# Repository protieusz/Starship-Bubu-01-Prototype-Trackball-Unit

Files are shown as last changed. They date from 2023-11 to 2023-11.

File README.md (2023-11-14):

# Starship-Bubu-01-Prototype-Trackball-Unit
Solo trackball unit powered by my Omega Supreme all in one PMW3660 sensor trackball, PER56, RP2040 integrated module.

Trackball ball support, encoder support and encoder knob support are all printed from Ariamelon's Kiwano VIK module in her GitHub.  

Initially this project was just going to be a working concept prototype and in the end it turns out to be a very functional working build.

Be warned: This project build requires lots of advanced soldering technical skills, lots of dexterityl, time and effort.

QMK source code was borrowed from Aki27's Bally build. I just copy and pasted most of it and adjust minor stuff. No support will be given since I am not well verse in QMK. 

In order to build this Starship Bubu, you would need the Bubu PCB itself and an OmegaSupreme REV 4 module which contains the RP2040 mcu, PMW3360 sensor and PER56 encoder.

# Starship Bubu-01 Prototype got featured on https://kbd.news/Starship-Bubu-OmegaSupreme-2184.html

Nov 11,2023 Update:

Upgraded with a janky case. 
https://www.instagram.com/p/CzhdMmdv5LE/?igshid=YzE4YTliZjNlMA==

Uploaded both STEP and STLs for the case.  I already lost a lot of brain cells designing the case.  Currently the case needs to be sandwiched hot glue together or whatever glue you use.  I hot glue just in case shit happens and I have to take apart and fix stuff.  You can modified the STEP files to your likely to make the case more secure.  I am not going to do any more tinkering with this prototype trackball anymore. Do so at your own risk.

As for the trackball support low profile holder, base PER56 encoder part and the ribbed knob please refer to AriaMelon's Kiwano GitHub for her 3DP STL files. https://github.com/Ariamelon/Kiwano/tree/main/3DP 

The trackball/RP2040 module aka the Omega Supreme I use for building the Starship Bubu-01 Prototype is from my OmegaSupreme Rev 4 https://github.com/protieusz/OmegaSupreme 
REV 4 with the corrected copper plated mount holes have been uploaded to the OmegaSupreme GitHub so print and assemble that one.  As always print at your own risk and for some reason when I install my PER56 encoder the footprint doesn't quite fit so I had to snip off the 2 black plastic anchors and bent one of the anchors a bit in order to fit in. Tight fit but it works.  The PER56 encoder was somehow flipped as per Sadek of Fingerpunch.  I don't feel like going back to flip the footprint and re-route again.  

Here is a picture from Sadek's Fingerpunch discord channel show which plastic anchors to snip off. [Fingerpunch](https://discord.com/channels/939959680611020840/1104738004574158968/1171529178949103666)

Screenshot 2023-11-12 at 12 56 26 AM

A full build guide will be uploaded soon.

Full Production Final Build Pics:





Build & Test Fit Process:










Starship Bubu PCB












Nov 3, 2023
Final product is still being testing and still waiting for PER56 encoder to arrive. Firmware working flawlessly. Once the PER56 final piece arrives, then Starship Bubu-01 Prototype will be fully assembled and ready.
Design gerbers will be made public and since this solo trackball is designed using EasyEDA, Kicad pcb file conversion will be a headache so the pcb file will not be released. However, schematic pdf and BOM will be release. The parts are manually hand solder so if you want to print this pcb, be prepared to advanced soldering skills to solder 0402 size components and lots of wiring soldering. Print and use as your own risk! No support will be provided. Please follow the below licensing if you want to modify, use, etc.  Omega Supreme module BOM and gerber files will be release if its own repository which will be updated later on.

Prototype Test Fit Look:



Fusion360 Design Render:

Screenshot 2023-10-26 at 3 34 44 PM

# License

</a></p>

You are free to:

Share — copy and redistribute the material in any medium or format

Adapt — remix, transform, and build upon the material

The licensor cannot revoke these freedoms as long as you follow the license terms.
Under the following terms:

Attribution — You must give appropriate credit, provide a link to the license, and indicate if changes were made. You may do so in any reasonable manner, but not in any way that suggests the licensor endorses you or your use.

NonCommercial — You may not use the material for commercial purposes.

ShareAlike — If you remix, transform, or build upon the material, you must distribute your contributions under the same license as the original.

No additional restrictions — You may not apply legal terms or technological measures that legally restrict others from doing anything the license permits.

Starship Bubu-01 Prototype by ProtieusKeebs is licensed under [CC BY-NC-SA 4.0](https://creativecommons.org/licenses/by-nc-sa/4.0/?ref=chooser-v1)

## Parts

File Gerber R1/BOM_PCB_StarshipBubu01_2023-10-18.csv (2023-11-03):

ID | Name | Designator | Footprint | Quantity | Manufacturer Part | Manufacturer | Supplier | Supplier Part | Price | link
1 |  | U13 | PL9823LED | 1
2 | NO | +5V,D+,D-,GND,GP6COL0,GP12COL1,GP13COL2,GP14ROW1,GP15ROW0,+5VOS,DINOS | PIN 1-PIN | 11
3 | PRTR5V0U2X,215 | D1-ESD | SOT-143_L2.9-W1.3-P1.92-LS2.3-BR | 1 | PRTR5V0U2X,215 | Nexperia(安世) | LCSC | C12333 | 0.162 | https://item.szlcsc.com/280548.html
4 | BSMD0805-020-15V | F1-FUSE | F0805 | 1 | BSMD0805-020-15V | BHFUSE(佰宏) | LCSC | C883103 | 0.045 | https://item.szlcsc.com/343298.html
5 | 5.1kΩ | R1-5.1K,R2-5.1K | R0402 | 2 | 0402WGF5101TCE | UNI-ROYAL(厚声) | LCSC | C25905 | 0.001 | https://item.szlcsc.com/323315.html
6 | TYPE-C-31-M-12 | USBC1 | USB-C_SMD-TYPE-C-31-M-12 | 1 | TYPE-C-31-M-12 | 韩国韩荣 | LCSC | C165948 | 0.216 | https://so.szlcsc.com/global.html?c=&k=C165948
7 | SM4007PL | D000,D002,D100,D101,D102 | SOD-123F_L2.8-W1.8-LS3.7-RD | 5 | SM4007PL | MDD | LCSC | C64898 | 0.007 | https://item.szlcsc.com/60254.html
8 | Switch | K000,K002,K100,K101,K102 | CHERRY_MX_100_MILLMAX | 5
9 |  | U14 | PL9823LED | 1

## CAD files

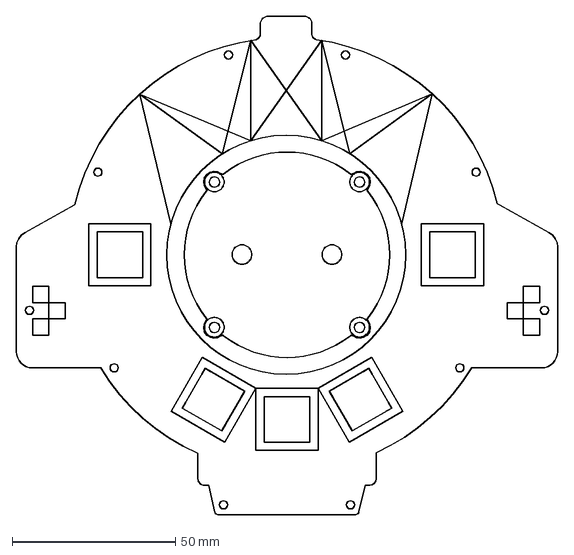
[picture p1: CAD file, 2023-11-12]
StarshipBubuPCBwHoles.dxf
166.0 x 152.8 mm

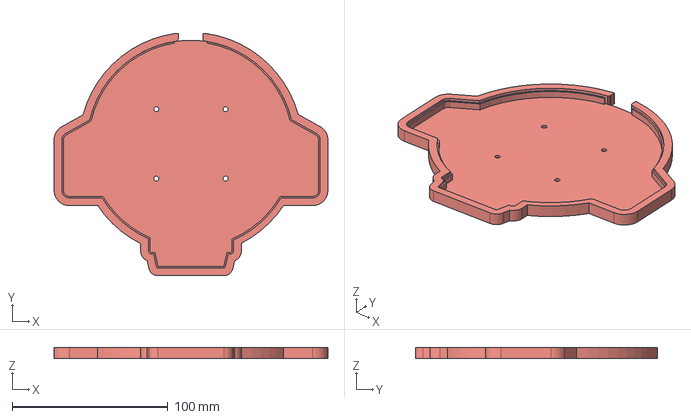
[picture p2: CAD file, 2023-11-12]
Case STEP/BubuBottomPlateCase.step
176.0 x 155.7 x 7.20 mm

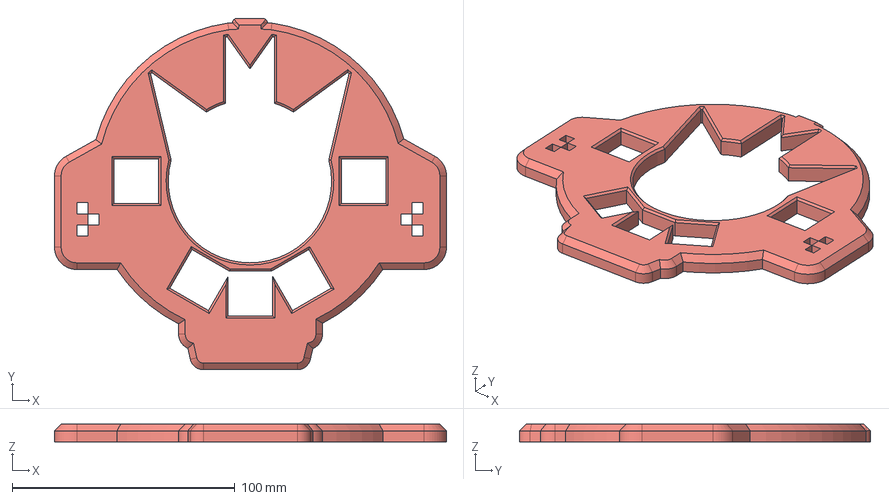
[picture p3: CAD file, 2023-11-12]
Case STEP/BubuTopCase.step
176.0 x 157.8 x 8.00 mm

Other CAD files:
Corrected STLs/BubuBottomPlateCase.stl
Corrected STLs/BubuTopCase.stl

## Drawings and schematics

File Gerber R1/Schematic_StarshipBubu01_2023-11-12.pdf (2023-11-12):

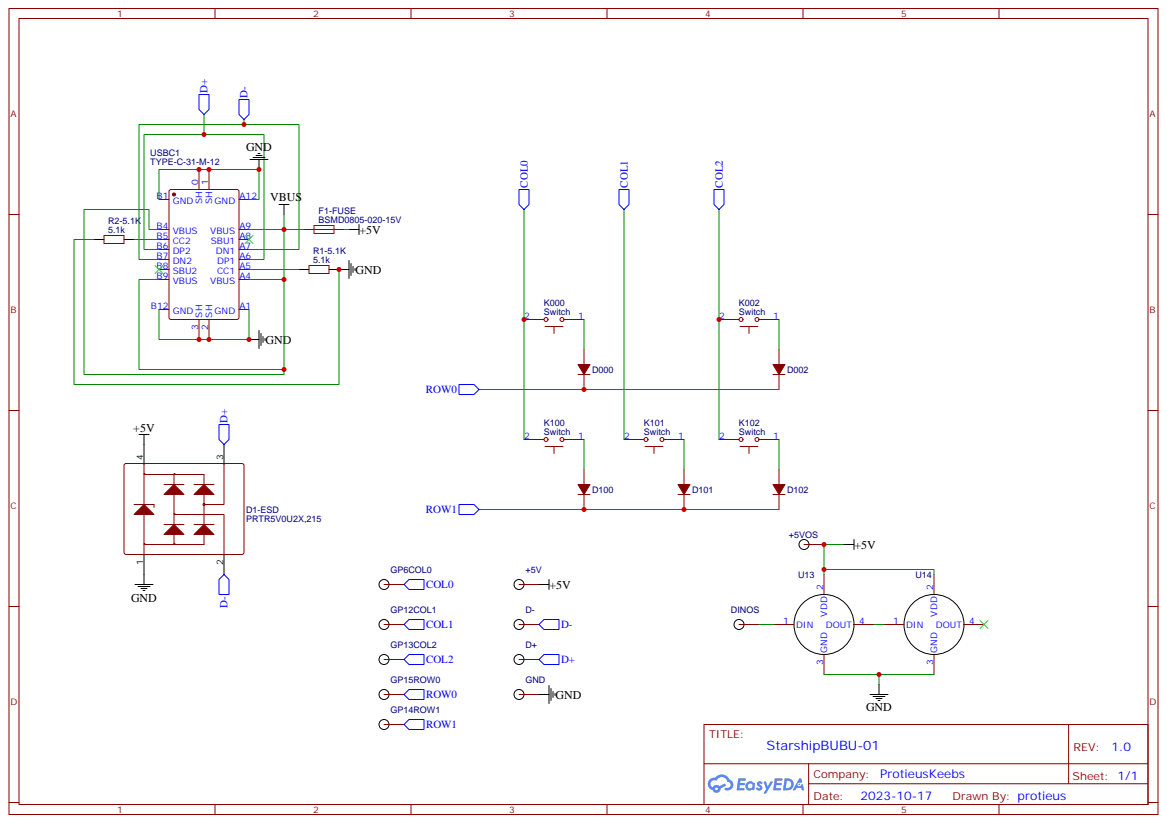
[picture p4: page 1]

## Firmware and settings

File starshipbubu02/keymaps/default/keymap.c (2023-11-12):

/*
Copyright 2022 aki27

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
You should have received a copy of the GNU General Public License
along with this program.  If not, see <http://www.gnu.org/licenses/>.
*/

#include QMK_KEYBOARD_H
#include <stdio.h>
#include "quantum.h"

enum combo_events {
  COMBO_RGBMOD,
  //COMBO_ESC,
  //COMBO_LENGTH
};
//uint16_t COMBO_LEN = COMBO_LENGTH;
#ifdef COMBO_ENABLE

const uint16_t PROGMEM combo_rgbmod[] = {KC_MS_BTN1, KC_MS_BTN2, COMBO_END};
//const uint16_t PROGMEM combo_esc[] = {KC_T, KC_G, COMBO_END};

combo_t key_combos[] = {
  [COMBO_RGBMOD] = COMBO(combo_rgbmod, RGB_MOD)
  //[COMBO_ESC] = COMBO(combo_esc, KC_ESC),
};
#endif

enum layer_names {
  _BASE,
  //_FN1,
  //_FN2,
  //_FN3
};

const uint16_t PROGMEM keymaps[][MATRIX_ROWS][MATRIX_COLS] = {
    
    [_BASE] = LAYOUT(

        CPI_SW,/*This is CPI setting, total of 5 setting slow to fast, press to toggle*/             RGB_TOG, 
        KC_MS_BTN1, SCRL_MO,/*This is scroll lock, press key & use trackball to scroll*/KC_MS_BTN2
    ) 
};


#if defined(ENCODER_MAP_ENABLE)
const uint16_t PROGMEM encoder_map[][NUM_ENCODERS][2] = {
    [0] =  { ENCODER_CCW_CW(KC_MS_WH_LEFT, KC_MS_WH_RIGHT)  }
    //[1] =  { ENCODER_CCW_CW(KC_MS_WH_LEFT, KC_MS_WH_RIGHT)  },
    //[2] =  { ENCODER_CCW_CW(KC_PGUP, KC_PGDN)  },
    //[3] =  { ENCODER_CCW_CW(KC_VOLD, KC_VOLU)  } 
    //[1] =  { ENCODER_CCW_CW(XXXXXXX, XXXXXXX) }
};
#endif

//keyevent_t encoder1_ccw = {
    //.key = (keypos_t){.row = 3, .col = 0},
    //.pressed = false
//};

//keyevent_t encoder1_cw = {
    //.key = (keypos_t){.row = 3, .col = 9},
    //.pressed = false
//};

//bool encoder_update_user(uint8_t index, bool clockwise) {
    //if (index == 0) { /* First encoder */
        //if (clockwise) {
            //encoder1_cw.pressed = true;
            //encoder1_cw.time = (timer_read() | 1);
            //action_exec(encoder1_cw);
        //} else {
            //encoder1_ccw.pressed = true;
            //encoder1_ccw.time = (timer_read() | 1);
            //action_exec(encoder1_ccw);
        //}
    //}

    //return true;
//}

//void matrix_scan_user(void) {

    //if (IS_PRESSED(encoder1_ccw)) {
        //encoder1_ccw.pressed = false;
        //encoder1_ccw.time = (timer_read() | 1);
        //action_exec(encoder1_ccw);
    //}

    //if (IS_PRESSED(encoder1_cw)) {
        //encoder1_cw.pressed = false;
        //encoder1_cw.time = (timer_read() | 1);
        //action_exec(encoder1_cw);
    //}

//}

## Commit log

2023-11-03 Gerbers, BOM, Components Placement files
    [BOM_PCB_StarshipBubu01_2023-10-18.csv, PickAndPlace_PCB_StarshipBubu01_2023-10-18.csv]
2023-11-12 Case Step files
    [BubuBottomPlateCase.step, BubuTopCase.step]
2023-11-12 STLs for print
    [BubuBottomPlateCase.stl, BubuTopCase.stl]
2023-11-12 Added schematic

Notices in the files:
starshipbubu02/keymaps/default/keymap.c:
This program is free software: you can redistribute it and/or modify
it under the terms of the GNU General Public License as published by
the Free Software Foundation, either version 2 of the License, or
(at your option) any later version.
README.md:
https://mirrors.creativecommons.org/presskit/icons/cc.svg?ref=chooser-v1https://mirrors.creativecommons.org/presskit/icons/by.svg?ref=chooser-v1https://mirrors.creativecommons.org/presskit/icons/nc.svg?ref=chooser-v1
